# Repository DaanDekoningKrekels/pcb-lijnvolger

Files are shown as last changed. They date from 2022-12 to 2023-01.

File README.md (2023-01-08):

# PCB Lijnvolger

## Snelle links

- [Opdrachtomschrijving](./oo2-opdrachtbeschrijving.pdf)
- [Onderzoeksdocument](./onderzoeksdocument.md)
- [PCB-ontwerp](./src/kicad-project/)
- [Testplan bestukken printplaat](testplan.md)

## Project structuur

```
.
├── assets                  (figuren)
├── datasheets              (datasheets gebruikte componenten)
└── src                     (alle bronbestanden)
    ├── kicad-project       (PCB-ontwerp)
    ├── LEDD0-test          (test voor LED Drivers)
    ├── SENSE-0-1-test      (test voor eerste sensoren)
    ├── TinyLijnvolger      (finale code)
    └── WIRE-test           (test voor I2C verbinding)
```

## Verslag PCB-lijnvolger

In deze repository kan alle informatie teruggevonden worden rond dit project.

Lijnvolger werking GIF

Het onderzoeksdocument beschrijft de algemene verwachtingen voor dit project en hoe ik van plan was het aan te pakken. Ik denk dat het onderzoek vrij goed aansluit met hoe het project uiteindelijk is verlopen. Het jammere is dat ik de meeste code niet heb kunnen testen omdat I2C niet werkt. Dit is echter een softwareprobleem en ligt niet aan het ontwerp van de printplaat.

schema lijnvolger pcb
schema lijnvolger sensoren pcb

Zo zou de PCB eruit zien:

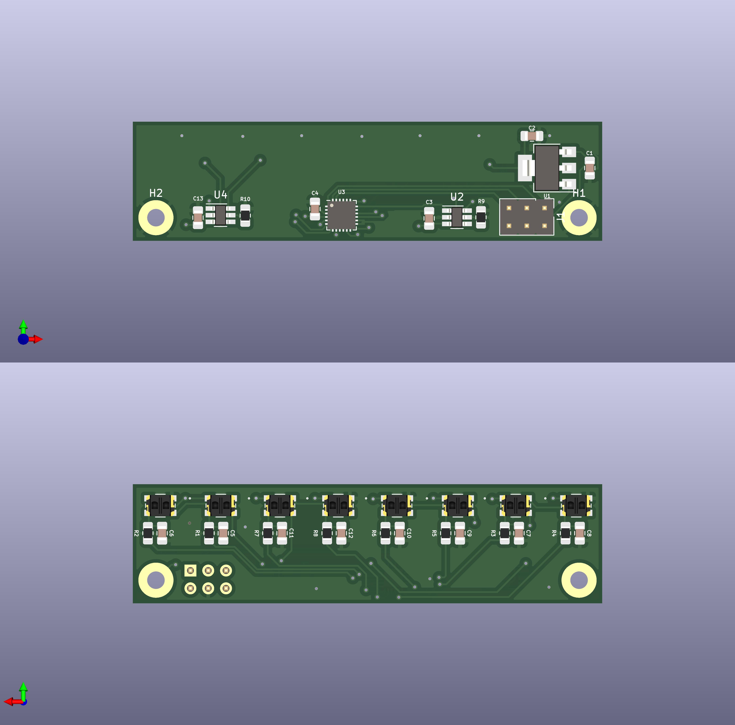
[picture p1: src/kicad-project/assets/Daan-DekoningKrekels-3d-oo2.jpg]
PCB lijnvolger render


Dit is hoe de definitieve printplaat eruit ziet:

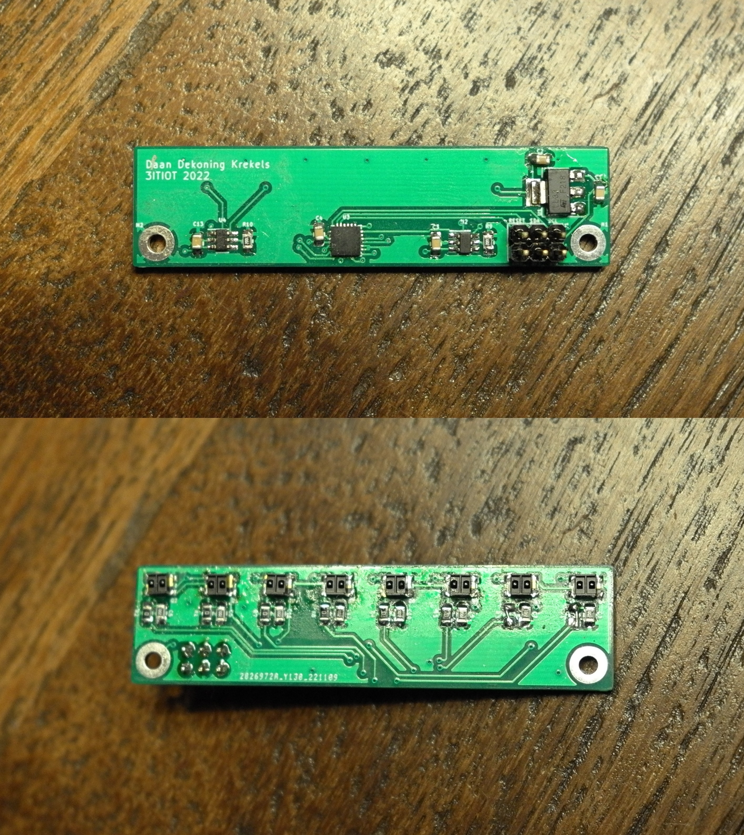
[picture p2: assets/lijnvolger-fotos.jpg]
fotos definitieve printplaat


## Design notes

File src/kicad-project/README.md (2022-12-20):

## Schema lijnvolger

Daan-DekoningKrekels-PCB-lijnvolgerDaan-DekoningKrekels-PCB-lijnvolger-sensors

## PCB lijnvolger

Daan-DekoningKrekels-3d-oo2

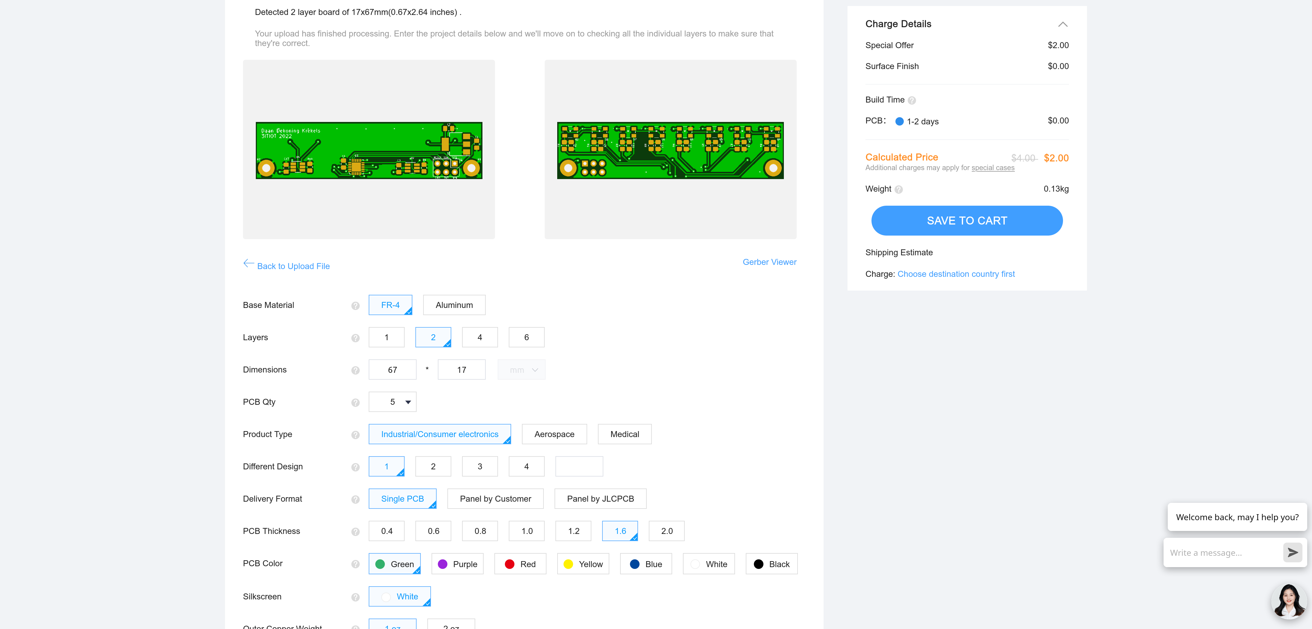
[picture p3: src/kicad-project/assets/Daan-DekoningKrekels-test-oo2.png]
Daan-DekoningKrekels-test-oo2


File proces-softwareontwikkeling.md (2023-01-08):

# Proces softwareontwikkeling

Zoals in het testplan te lezen is werd niet alle software in 1x geschreven. Er moesten incrementeel delen (individueel) getest worden om te weten of alles naar behoren werkt.

## Enkel MCU

Voor het programmeren van de MCU via de Arduino IDE is gekozen voor de [megaTinyCore](https://github.com/SpenceKonde/megaTinyCore) boardfiles. Dit project is immens goed gedocumenteerd en alles is terug te vinden op de eerder gelinkte GitHub pagina.

Het programmeren zelf verloopt via [jtag2updi](https://github.com/ElTangas/jtag2updi), een tool die het mogleijk maakt om met een Arduino NANO een UPDI microcontroller te programmeren. magaTinyCore heeft ondersteuning om jtag2updi als programmer te gebruiken. 

De code die hier gebruikt is is een simpele blinky op PC1. Dat is een pad voor een van de LED drivers dus ik kon met een multimeter gemakkelijk de spanning meten.

## I²C testen

Jammer genoeg is het mij niet gelukt om dit aan de praat te krijgen. Omdat ik de standaard TWI pinnen (PB0 en PB1) verkozen had voor de photointerruptors heb ik de ALT pinnen naar buiten gebracht om langs te verbinden.

Om een of andere reden is het mij echter niet gelukt om een I²C verbinding tot stand te brengen. Ik heb verschillende mogelijkheden getest en om de I²C verbinding te controleren heb ik een ESP32 gebruikt met een adres scanner. 

De Wire bibliotheek van megaTinyCore heeft een aantal extra functies om het gebruik van de alternatieve pinnen te faciliteren. ([documentatie](https://github.com/SpenceKonde/megaTinyCore/blob/master/megaavr/libraries/Wire/README.md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))
- `Wire.pins()` biedt de mogelijkheid om alternatieve pinnen expliciet aan te wijzen
  - De enige pinnen die hier kunnen worden meegegeven zijn de standaard TWI pinnen (PB0 en PB1) en de alternatieve pinnen (PA1 en PA2).
- `Wire.swap(n)` biedt de mogelijkheid ui te wisselen tussen een aantal voorgedefinieerde pinouts.
  - Voor de MCU die wij gebruiken is enkel `swap(0)` en `swap(1)` beschikbaar. 

Beide opties hebben I²C niet werkende gekregen in mijn geval. Als alternatief heb ik gezocht naar een manier om zelf de juiste pinout in te schakelen met een registermanipulatie. Die heeft echter ook niet geholpen. Op plaats 4 in het `PORTMUX` register `CTRLB` kan de alternatieve pinout worden ingeschakeld.

PORTMUX.CTRLB register

Als laatste redmiddel heb ik TinyCore geprobeerd. Die Wire bibliotheek biedt ook een manier om de alternatieve pinout te gebruiken. ([documentatie](https://docs.tinycore.dev/en/latest/usage.html#i2c)) 

`WIRE-test.ino`
```c++
// Wire Slave Sender

#include <Wire.h>

void setup() {
  // Deze functie zou de alternatieve pinout moeten activeren.
  // Wire.pins(18, 19);
  Wire.pins(PIN_PA1, PIN_PA2); 
  // Deze functie zou dit ook moeten doen
  Wire.swap(1); 
  // TWI ALT - Deze register schakelt de alternatieve pinout volgens de datasheet in
  PORTMUX.CTRLB |=   1 << 4; 

  // TinyCore: wisselen met alternatieve TWI pinnen
  Wire.useAlternatePins(); 

  Wire.begin(0x55);              // join i2c bus met adres 0x55
  Wire.onRequest(requestEvent);  // register event
}

void loop() {
  delay(100);
}

// function that executes whenever data is requested by master
// this function is registered as an event, see setup()
void requestEvent() {
  Wire.write("oi");  // respond with message of 2 bytes
  // as expected by master
}
```

## Photointerrupter testen

Ik heb telkens twee fotointerrupters in serie staan met elkaar dus ik ben gestart met één serieschakeling van de fotointerrupters te bestukken en testen. Met een camera is te zien of de LED's oplichten.

Later heb ik de code uitgebreid om ook de tweede LED-driver te testen.

```c++
#define LEDD0 13  // PC1
#define LEDD1 14  // PC2

void setup() {
  pinMode(LEDD0, OUTPUT);
  pinMode(LEDD1, OUTPUT);
}

void loop() {
  // put your main code here, to run repeatedly:
  digitalWrite(LEDD0, LOW); // IR LEDS gaan aan
  delay(500);
  digitalWrite(LEDD0, HIGH); // IR LEDS gaan uit
  delay(500);
  digitalWrite(LEDD1, LOW); // IR LEDS gaan aan
  delay(500);
  digitalWrite(LEDD1, HIGH); // IR LEDS gaan uit
  delay(500);
}
```

## Alles samenbrengen

In de finale code zal de lijnvolger een slave zijn waar de master een byte naar kan sturen om een bepaalde werkingsmodus in te schakelen of een aanvraag sturen om de data van de photointerruptors door te krijgen.

Via het `Wire.print()` statement zal een char array verstuurd worden. In deze char array zitten de actuele waardes van de photointerruptors.

Er zijn 4 modi beschikbaar:
1. `FAST_DIGITAL`: De IR LED's daar altijd aan staan en de master zal een byte array krijgen met 1en en 0en per sensor.
2. `FAST_ANALOG`: De IR LED's daar altijd aan staan en de master zal een byte array krijgen met de ADC waarde per sensor.
3. `ANALOG`: De IR LED's worden ingeschakeld op aanvraag en de master krijgt een byte array met de ADC waarde per sensor.
4. `DIGITAL`: De IR LED's worden ingeschakeld op aanvraag en de master krijgt een byte array met 1en en 0en per sensor.

De FAST-modi kunnen gebruikt worden om bijvoorbeeld sneller data te ontvangen waar de master nog een gemiddeldeberekening op uitvoert.

Idealiter zouden de DIGITAL-modi maar één byte doorsturen met op iedere bit de digitale waarde van de corresponderende photointerruptor.

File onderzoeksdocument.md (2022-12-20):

# Onderzoeksdocument – Lijnvolger

*Daan Dekoning Krekels*

## Geef een kritische analyse van je vorige PCB

> Werkte de PCB, heb je deze kunnen programmeren en data kunnen versturen over de I2C. 
>
> Als dit niet lukte, geef ook weer waarom.

Informatie over mijn printplaat kan je hier terugvinden: https://daandekoningkrekels.github.io/SmartSystems-RobotWagen/sensor-module/

Informatie over de bijhorende code hier: https://daandekoningkrekels.github.io/SmartSystems-RobotWagen/code/#sensor-module

Mijn PCB werkte niet, ik heb deze niet kunnen programmeren.

Over het algemeen denk ik dat de PCB vrij goed is gelukt eens de via's en clearances correct waren ingesteld.

Een grote moeilijkheid bij het bestukken van de print was dat er geen via's meer beschikbaar waren op school. De via's moest handmatig worden gemaakt door een stukje kabel te solderen in ieder gat. Hier had ik op voorhand geen weet van en dat resulteerde in het probleem dat bijvoorbeeld onder de microcontroller een aantal vias aanwezig zijn, die maken dat de MCU niet mooi vlak op de PCB staat en dat kan misschien op de lange termijn voor connectieproblemen zorgen.

KiCad gaat er, met de huidige instellingen, vanuit dat de gaten van through hole componenten beide kanten van de printplaat met elkaar verbinden. Dat is niet het geval waardoor ik bijvoorbeeld pin-headers en het through-hole kristal langs beide kanten moest solderen.

Het had beter geweest als ik op voorhand rekening had gehouden met deze beperkingen zodat ik geen via’s onder een IC heb en geen banen naar beide kanten van through-hole componenten.

Op volgende foto zie je dat mijn kristal iets hoger staat, dat is omdat ik langs beide kanten heb moeten solderen. Hetzelfde geldt voor de pinheaders, daarbij heb ik eerst de plastic isolatie naar boven gedaan en na het solderen terug tegen mijn printplaat gedrukt.

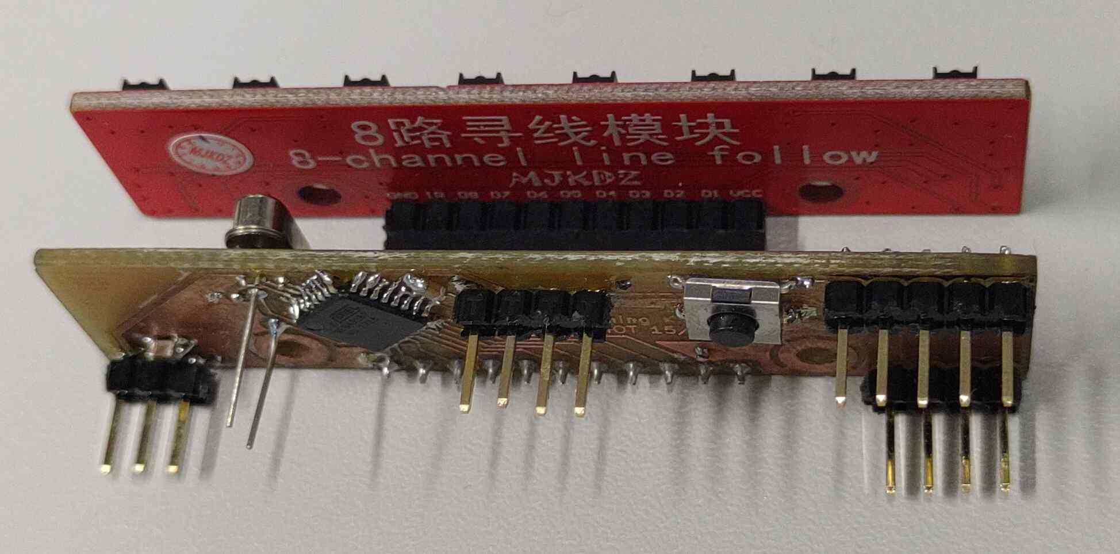
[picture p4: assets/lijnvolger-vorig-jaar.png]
 

## Welke aanpassing zou je maken in V2 i.k.v. de Smart Systems opdracht

> Als je nog een iteratie zou maken voor de opdracht van Smart Systems (niet PCB Design Advanced) welke verbeteringen zou je dan aanbrengen 

Als we de PCB terug zouden moeten frezen op school, zou ik meer rekening houden met de limietringen die daarbij van toepassing zijn. Zo zou ik bij pinheaders maar langs één kant banen trekken en via’s eerder in het midden van het bord zetten ipv. onder een IC. 

Op vlak van documentatie zou ik, als de PCB werkt, ook een gedetailleerde handleiding maken over hoe de bootloader kan geflasht worden.

Ik ben fan van de vormfactor dus die zou ik zeker behouden.

## Als je code hebt geschreven voor je project, voeg deze ook toe als zip 

> GitHub of andere online git repo is ook toegelaten

Informatie over de bijhorende code hier: https://daandekoningkrekels.github.io/SmartSystems-RobotWagen/code/#sensor-module

## Welke componten wordt er gebruikt ter detectie van lijn

> Zoek uit welke component er gebruik kan worden voor de lijn detectie. Zoek een zo gelijkaardige component. Voorzie een link naar een mogelijk leverancier (Farnell, Mouser, Digi-Key)

https://nl.farnell.com/sharp/gp2s700hcp/photointerrupter/dp/1618426

De MIR-3.0Y module bezit over 8 infrarood sensoren. Dit is een enkele component waarin een infrarood led zit en een infrarood phototransistor.

Een lijnvolger kan ook beschikken over een LED-driver. Die zorgt ervoor dat er altijd dezelfde stroom vloeit door de LED’s waardoor de helderheid constant is, ookal varieert de ingangsspanning. Een constante helderheid is belangrijk wanneer we de reflectie willen meten, de weerstand van de fototransistor zou anders totaal verkeerd zijn ten opzichte van de afstand.

## Op welke manieren kan de lijndetectie component worden aangestuurd

> Er zijn twee mogelijke manier om de lijn detectie module uit te lezen. Welke zijn dit? 
>
> Geef ook de nodige conditioneringscircuit om dit te doen, m.a.w. het deelschema rond de lijn detectie component 

Je kan lijnvolger-data op een digitale of analoge manier interpreteren. De fototransistor die in de sensor zit geeft een analoge spanning afhankelijk van de reflectie van het infrarood licht. Bij het andere type zal het logische niveau veranderen.

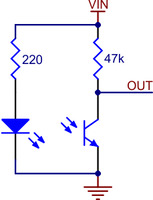
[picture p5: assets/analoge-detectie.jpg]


Er zijn verschillende manieren om dit te verwezenlijken. Voor de analoge spanning kan de uitgang van de fototransistor door een ADC gelezen worden. Door de Weerstand die naar de VIN gaat ontstaat er een spanningsdeler en zal dus de uitgangsspanning afhangen van de weerstand die de transistor heeft. Deze weerstand is uiteraard afhankelijk van de reflectie.

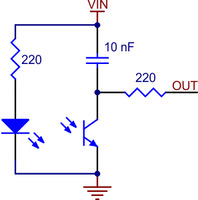
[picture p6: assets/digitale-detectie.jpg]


Voor de logische niveaus kan er gebruik gemaakt worden van een condensator naar de VIN. Wanneer er een puls gestuurd wordt vanuit de MCU zal de condensator opladen en geleidelijk aan weer ontladen, afhankelijk van de weerstand van de fototransistor. Door de lengte van deze ontlading te meten kunnen we achterhalen wat de reflectie is.

De analoge versie kan echter ook op andere manieren gebruikt worden. Zo kunnen we een normale digitale ingang gebruiken om zo de logische niveaus te weten. Hierbij hangen we af van wanneer de MCU een lijn als hoog of als laag beschouwt. Een andere optie is om een comparator te gebruiken en zo de analoge spanning om te zetten naar een hoge of lage uitgang.

Voor de printplaat kunnen we in principe opteren voor beide. Als de footprints worden voorzien voor de digitale schakeling kan, indien gewenst, ook enkel de pull-up weerstand worden geïnstalleerd en het andere pad kan met een 0 Ohm weerstand bestukt worden.

## Welke pinnen worden er gebruikt in mijn design en waarom

> Vele pinnen van een microcontroller hebben meestal een dubbele functionaliteit. In dit vooronderzoek ga je kijken welke pinnen het veiligste zijn om te gebruiken.

Om de lijnvolger aan te sluiten ga ik gebruik maken van **PA4**, **PA5**, **PA6**, **PA7**, **PB5**, **PB4** en **PB1**. De enable van de lijnvolger sluit ik aan op **PB0**.

De bedoeling is om met één enkele lijn code op te halen welke digitale pinnen hoog of laag zijn. Dat kan dan ook worden opgeslagen in één enkele byte.

Diezelfde byte kan gebruikt worden om via bit checking na te gaan welke sensor geactiveerd is.

**PA1** en **PA2** worden gebruikt voor de USART verbinding. Deze pinnen ondersteunen ook I²C dus dat is achteraf ook een mogelijkheid, mits toevoeging pull-up weerstand.

Voor UPDI zal **PA0** worden vrijgehouden en beschikbaar gemaakt via testpads.

De MAX6970AAE+ LED controller zorgt ervoor dat de LED’s, onafahanelijk van de ingangsspanning een constante helderheid hebben. Deze IC communiceert via SPI dus zal aangesloten worden op SCK = **PC0**, MISO = **PC1**, MOSI = **PC2**, load-enable = **PC3** en output-enbale = **P****B3**. Met een 360 Ohm weerstrand aan de SET pin zal de LED controller 50mA per LED toestaan. Deze waarde kan uiteraard worden ingesteld naar eigen wensen.

Load-Enable Input. Data is loaded transparently from the internal shift register to the output latch while LE is high. Data is latched into the output latch on LE’s falling edge and retained while LE is low.

Output-Enable Input. High forces outputs OUT0 to OUT7 high impedance without altering the contents of the output latches. Low enables outputs OUT0 to OUT7 to follow the state of the output latches.

## Hoe programmeer ik de microcontroller

> Onderzoek hoe je de microcontroller kan programmeren en werk dit praktisch uit

Net zoals de AtTiny 1616 ondersteunt de 3216 ook UPDI.

De ATtiny beschikt over een UPDI of Unified Program and Debug Interface. Deze biedt de mogelijkheid om via één enkele aansluiting de MCU te programmeren. Omdat deze aansluiting via de RESET pin gebeurt, geven we hier ook geen enkele GPIO pin voor op.

Deze interface biedt ook de mogelijkheid tot een   
 half-duplex UART-verbinding op te zetten om bijvoorbeeld debug informatie te kunnen tonen.

Voor het programmeren via deze interface hebben we minstens toegang nodig tot de RESET pin, VDD en GND. De Atmel-ICE kan gebruikt worden om het programma naar de MCU te schrijven.

## Welke clockconfiguratie gebruikt mijn design en waarom

> Een microcontroller heeft meestal verschillende opties voor het aansturen van interne clockmodel. Licht toe welke optie je gaat gebruiken en waarom. 

Omdat het geen concrete benodigdheid is om zo energiezuinig mogelijk te zijn zou ik gebruik maken van de interne 20MHz klok.

## Hoe wordt de PCB van stroom voorzien?

> Op welk spanningsniveau zal je PCB werken, Hoe ga je het correcte voltage voorzien aan de horloge. 

De PCB zal voorzien worden van de LDL1117S50R 5 V spanningsregelaar. De ingangsspanning kan dus 5,35 V tot 18 V bedragen. Overtollige spanning wordt in een lineaire regelaar afgestaan als warmte waardoor bij hoge spanningen ook hoge temperaturen gepaard gaan.

Er is gekozen voor een spanningsregelaar zodat deze rechtstreeks mee op de PCB kan staan, dicht bij de andere componenten. Zo vermijden we onstabiele en onbetrouwbare spanningen.

Echter, zal er ook een aansluiting zijn om rechtstreeks 5 V aan de PCB te voeden. Dit maakt de PCB toegankelijker bij gebruik met bijvoorbeeld een Arduino.

Uiteraard wordt ook voor iedere component een eigen ontkoppelcondensator voorzien zodat deze een stabiele ingangsspanning hebben.

## Bronnen

https://www.tinytronics.nl/shop/en/sensors/optical/infrared/8x-ir-line-tracking-module-40mm-range

https://www.pololu.com/product/4541

https://www.pololu.com/docs/0J19/1

## Datasheets:

Alle datasheets zijn ook beschikbaar in KiCad als je op een component staat en de 'D' indrukt.

https://datasheets.maximintegrated.com/en/ds/MAX6970.pdf

https://www.farnell.com/datasheets/53142.pdf

http://ww1.microchip.com/downloads/en/DeviceDoc/ATtiny3216-17-DataSheet-DS40002205A.pdf

https://www.farnell.com/datasheets/2259188.pdf

https://ww1.microchip.com/downloads/en/Appnotes/AN2519-AVR-Microcontroller-Hardware-Design-Considerations-00002519B.pdf

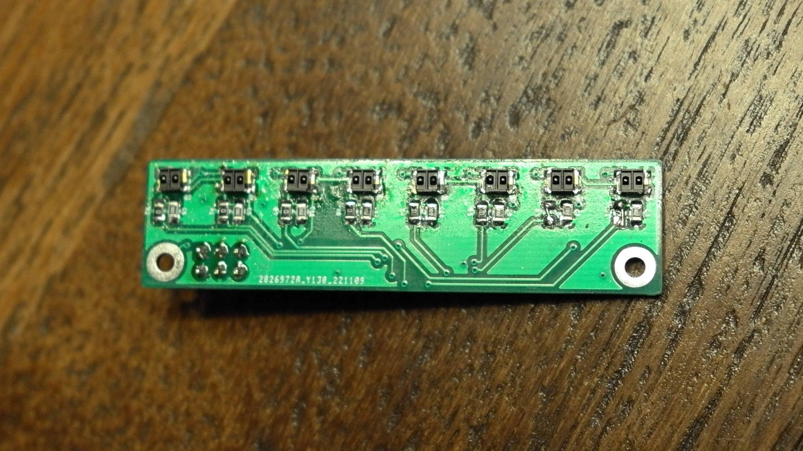
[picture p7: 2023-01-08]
assets/foto-onderkant.JPG

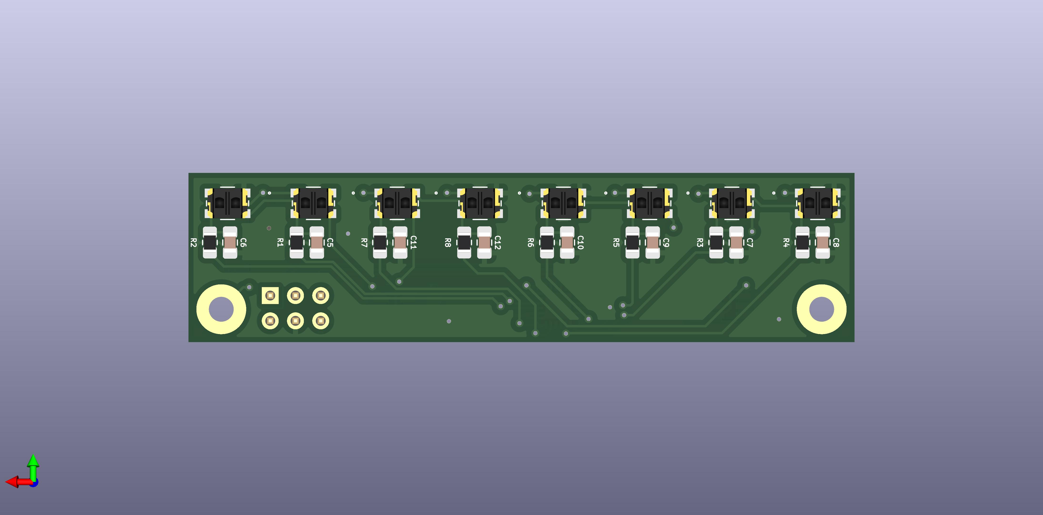
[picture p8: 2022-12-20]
src/kicad-project/assets/PCB-lijnvolger-onderkant.jpg

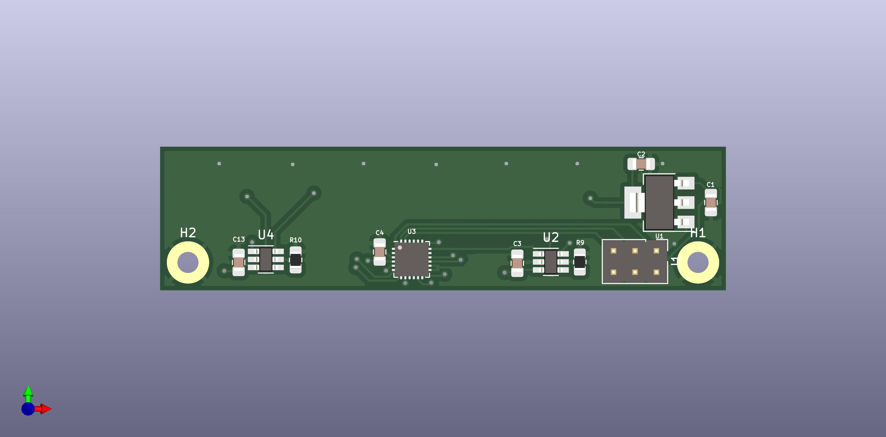
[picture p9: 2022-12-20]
src/kicad-project/assets/PCB-lijnvolger-bovenkant.jpg

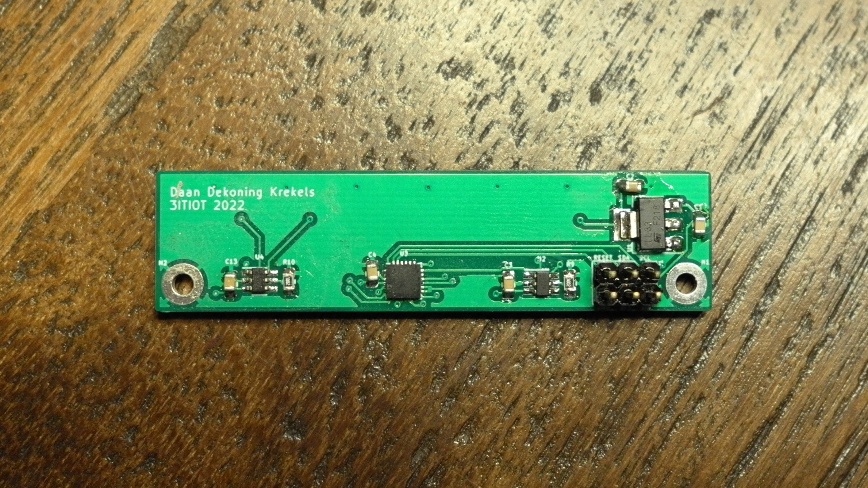
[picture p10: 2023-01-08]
assets/foto-bovenkant.JPG

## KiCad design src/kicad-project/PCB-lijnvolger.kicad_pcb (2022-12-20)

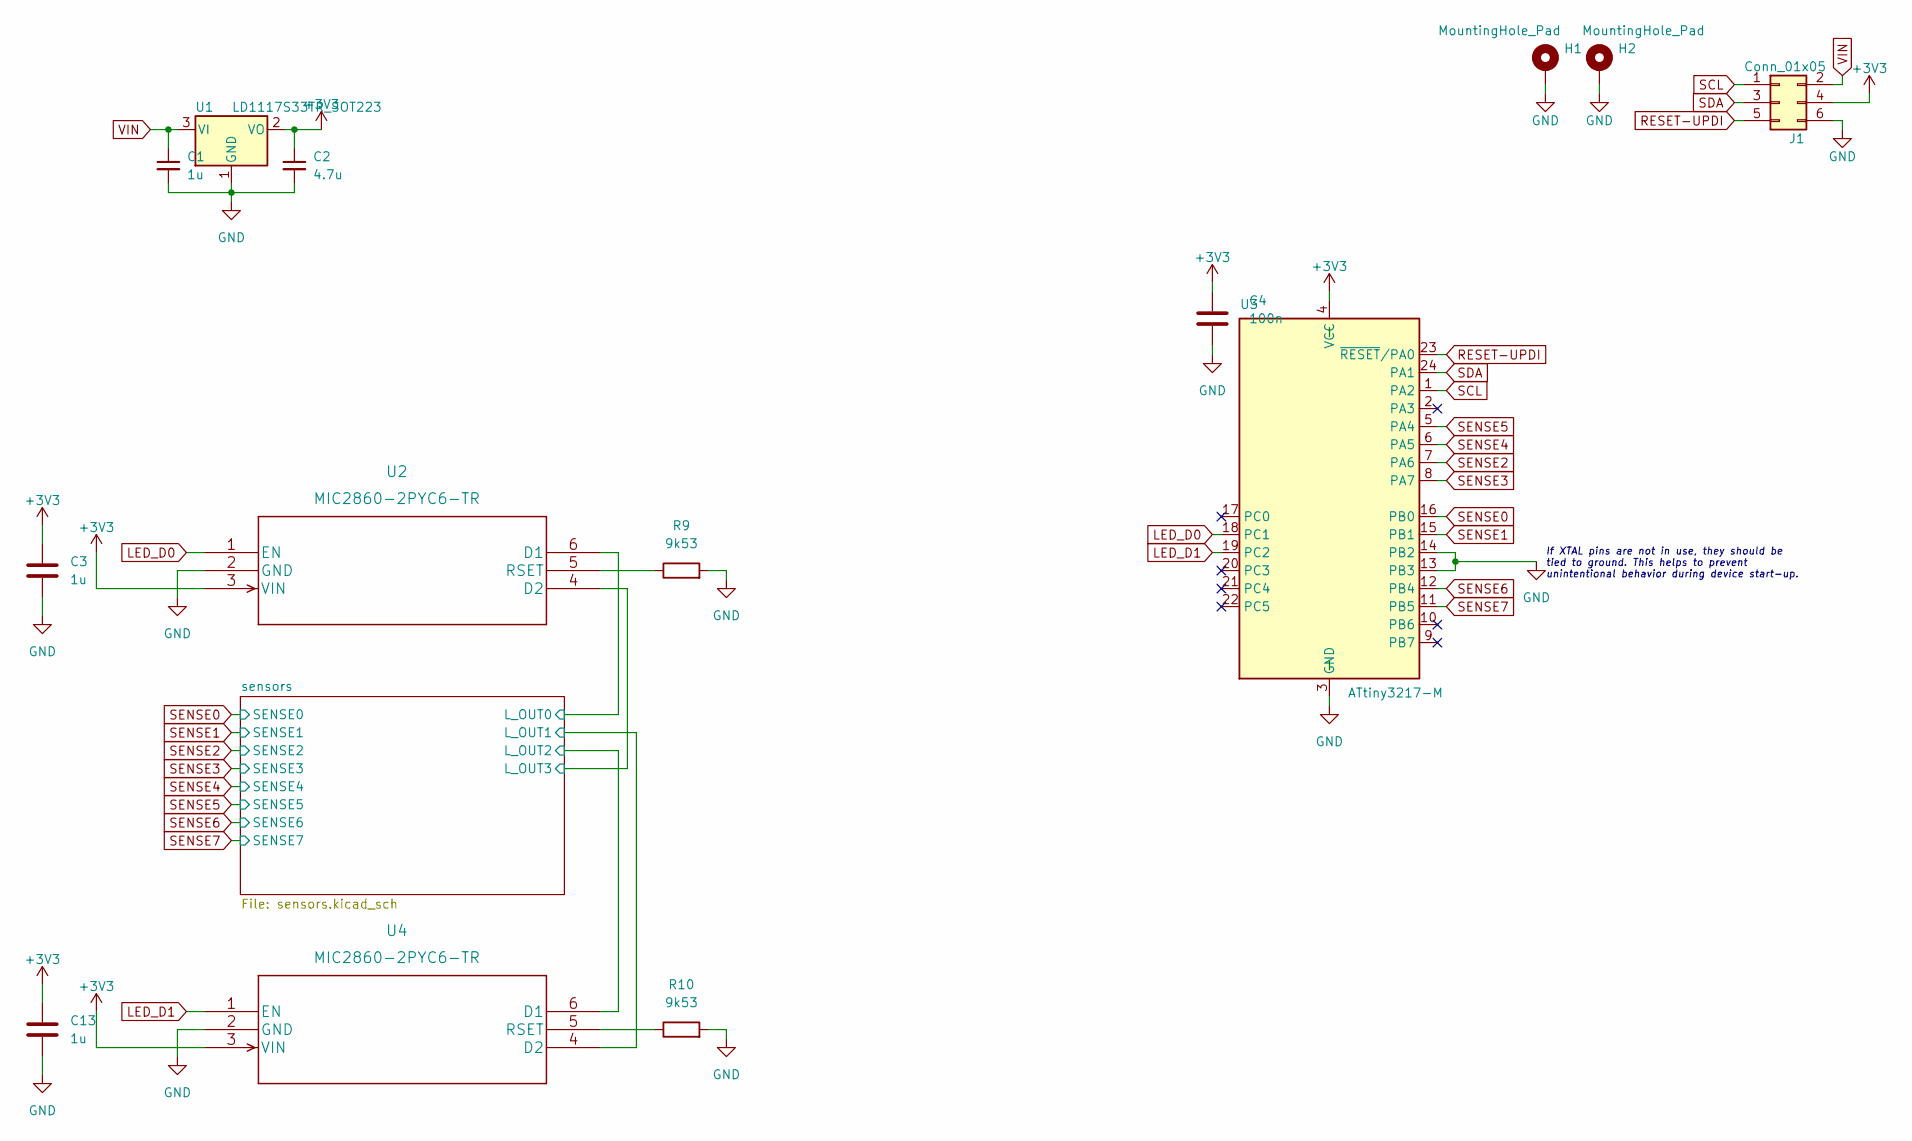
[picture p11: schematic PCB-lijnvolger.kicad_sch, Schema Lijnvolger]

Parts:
C1, C3, C13: 1u; C_0805_2012Metric_Pad1.18x1.45mm_HandSolder
C2: 4.7u; C_0805_2012Metric_Pad1.18x1.45mm_HandSolder
C4: 100n; C_0805_2012Metric_Pad1.18x1.45mm_HandSolder
H1, H2: MountingHole_Pad; MountingHole_2.5mm_Pad
J1: Conn_01x05; PinHeader_2x03_P2.54mm_Vertical
R9, R10: 9k53; R_0805_2012Metric_Pad1.20x1.40mm_HandSolder
U1: LD1117S33TR_SOT223; SOT-223-3_TabPin2
U2, U4: MIC2860-2PYC6-TR; SOT-23-6_Handsoldering
U3: ATtiny3217-M; QFN-24-1EP_4x4mm_P0.5mm_EP2.6x2.6mm

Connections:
+3V3: C2.1, C3.1, C4.1, C13.1, J1.4, U1.2 (VO), U2.3 (VIN), U3.4 (VCC), U4.3 (VIN); also elsewhere on the board
/sensors/L_OUT0: U2.6 (D1); also elsewhere on the board
/sensors/L_OUT1: U4.4 (D2); also elsewhere on the board
/sensors/L_OUT2: U4.6 (D1); also elsewhere on the board
/sensors/L_OUT3: U2.4 (D2); also elsewhere on the board
GND: C1.2, C2.2, C3.2, C4.2, C13.2, H1.1, H2.1, J1.6, R9.2, R10.2, U1.1 (GND), U2.2 (GND), U3.3 (GND), U3.13 (PB3), U3.14 (PB2), U3.25 (GND), U4.2 (GND); also elsewhere on the board
LED_D0: U2.1 (EN), U3.18 (PC1)
LED_D1: U3.19 (PC2), U4.1 (EN)
unnamed: R9.1, U2.5 (RSET)
unnamed: R10.1, U4.5 (RSET)
RESET-UPDI: J1.5, U3.23 (~RESET/PA0)
SCL: J1.1, U3.1 (PA2)
SDA: J1.3, U3.24 (PA1)
SENSE0: U3.16 (PB0); also elsewhere on the board
SENSE1: U3.15 (PB1); also elsewhere on the board
SENSE2: U3.7 (PA6); also elsewhere on the board
SENSE3: U3.8 (PA7); also elsewhere on the board
SENSE4: U3.6 (PA5); also elsewhere on the board
SENSE5: U3.5 (PA4); also elsewhere on the board
SENSE6: U3.12 (PB4); also elsewhere on the board
SENSE7: U3.11 (PB5); also elsewhere on the board
VIN: C1.1, J1.2, U1.3 (VI)

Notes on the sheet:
If XTAL pins are not in use, they should be tied to ground. This helps to prevent unintentional behavior during device start-up.

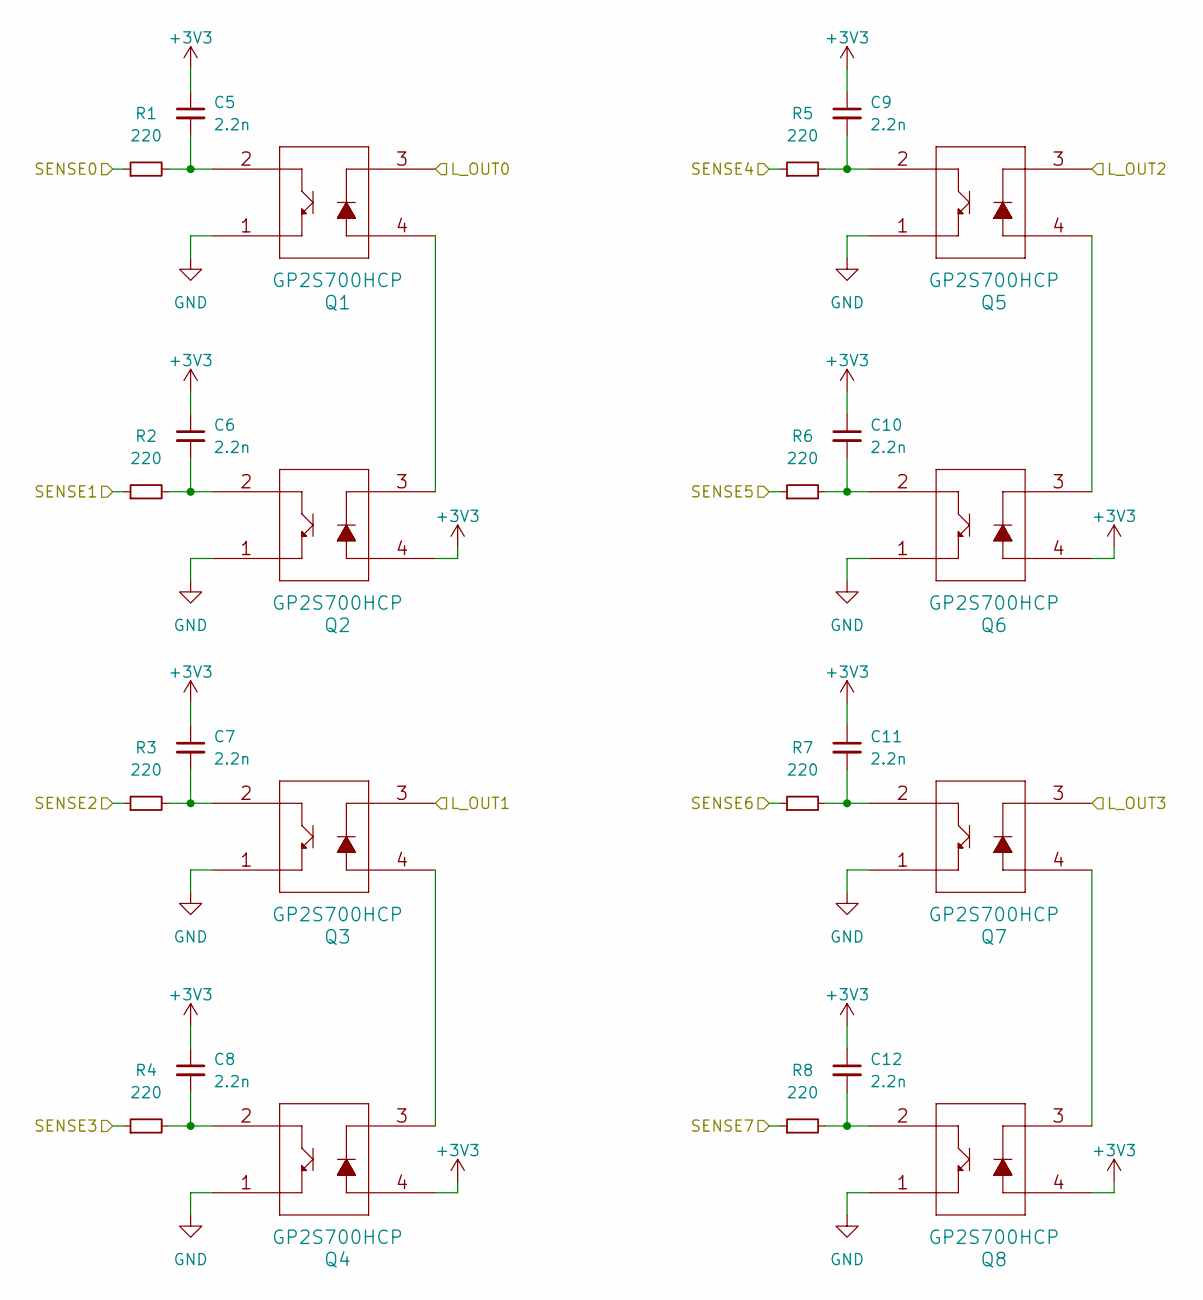
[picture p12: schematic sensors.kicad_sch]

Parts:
C5, C6, C7, C8, C9, C10, C11, C12: 2.2n; C_0805_2012Metric_Pad1.18x1.45mm_HandSolder
Q1, Q2, Q3, Q4, Q5, Q6, Q7, Q8: GP2S700HCP
R1, R2, R3, R4, R5, R6, R7, R8: 220; R_0805_2012Metric_Pad1.20x1.40mm_HandSolder

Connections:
+3V3: C5.1, C6.1, C7.1, C8.1, C9.1, C10.1, C11.1, C12.1, Q2.4, Q4.4, Q6.4, Q8.4; also elsewhere on the board
/sensors/L_OUT0: Q1.3; also elsewhere on the board
/sensors/L_OUT1: Q3.3; also elsewhere on the board
/sensors/L_OUT2: Q5.3; also elsewhere on the board
/sensors/L_OUT3: Q7.3; also elsewhere on the board
GND: Q1.1, Q2.1, Q3.1, Q4.1, Q5.1, Q6.1, Q7.1, Q8.1; also elsewhere on the board
unnamed: C5.2, Q1.2, R1.2
unnamed: C6.2, Q2.2, R2.2
unnamed: C7.2, Q3.2, R3.2
unnamed: C8.2, Q4.2, R4.2
unnamed: C9.2, Q5.2, R5.2
unnamed: C10.2, Q6.2, R6.2
unnamed: C11.2, Q7.2, R7.2
unnamed: C12.2, Q8.2, R8.2
unnamed: Q1.4, Q2.3
unnamed: Q3.4, Q4.3
unnamed: Q5.4, Q6.3
unnamed: Q7.4, Q8.3
SENSE0: R1.1; also elsewhere on the board
SENSE1: R2.1; also elsewhere on the board
SENSE2: R3.1; also elsewhere on the board
SENSE3: R4.1; also elsewhere on the board
SENSE4: R5.1; also elsewhere on the board
SENSE5: R6.1; also elsewhere on the board
SENSE6: R7.1; also elsewhere on the board
SENSE7: R8.1; also elsewhere on the board

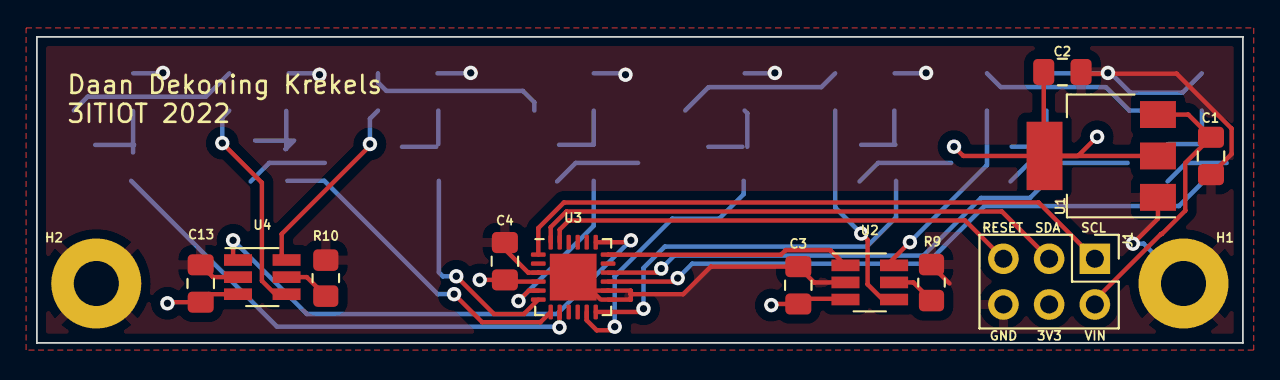
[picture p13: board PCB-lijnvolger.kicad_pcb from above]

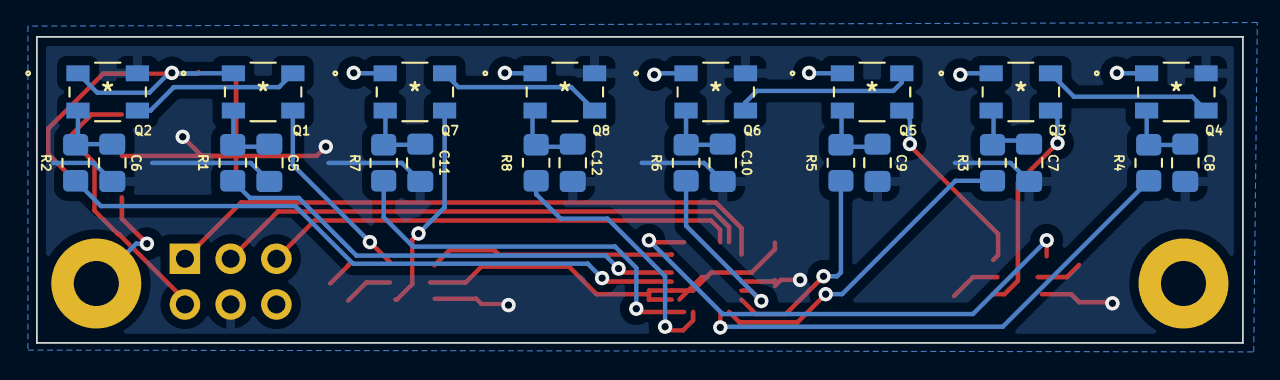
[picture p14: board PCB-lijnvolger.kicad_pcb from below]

Board: 2 copper layers, 67.0 x 17.0 mm, 38 parts (24 on the bottom side), 34 nets.

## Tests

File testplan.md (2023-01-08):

# Testplan PCB Lijnvolger

| **Volgorde** | **Fase** | **Taak of Test** | **Component** | **Beschrijving** | **Done, pass, fail** | **Opmerking** |
| --- | --- | --- | --- | --- | --- | --- |
| 1 | Power supply | Taak | U1, C1, C2 | Bestukken spanningsregelaar en ontkoppelcondensatoren. | Done | |
| 3 | Power supply | Test | U1, C1, C2 | Testen spanningsregelaar door een voeding van 5V te voorzien aan de VIN pin en 3,3V te meten aan de uitgang van de regelaar. | Done | Zonder problemen vanaf de eerste keer gelukt |
| 3 | MCU | Taak | U3, C4 | Bestukken MCU en ontkoppelcondensator. | Done | Het bestukken van de MCU ging niet goed bij de eerste keer. VCC en GND waren kortgesloten dus ik heb de MCU vervanger door een nieuwe na het desolderen. Bij het desolderen zijn ook wat paden mee losgekomen waardoor ik een nieuw exemplaar van mijn pcb heb moeten gebruiken. Ik heb bestukt met hetelucht. |
| 2 | MCU | Test | U3, C4 | Testen MCU door deze te programmeren met Arduino als UPDI programmer. | Done | Bij de tweede keer proberen is het gelukt. |
| 4 | MCU | Test | U3 | Testen of I2C verbinding tot stand kan komen met een andere MCU. | Fail | Het is me niet gelukt om I²C aan te praat te krijgen. Ik maak gebruik van de alternatieve TWI pinnen maar ik heb deze niet kunnen gebruiken. |
| 5 | LED drivers | Taak | U2, U4, C3, C13 | Bestukken LED drivers en ontkoppelcondensatoren. | Done | Ik heb de LED drivers probleemloss met een soldeerbout bestukt. |
| 6 | LED drivers | Test | U2, U4, C3, C13 | Testen LED drivers door een programma te schrijven voor de MCU die de leds laat pinken. Met een oscilloscoop is dan de spanning af te lezen, met een multimeter kan de kortsluitstroom gemeten worden om te zien of I_led goed is ingesteld. | Done | Ik heb de uitgang van de LED drivers gemeten met een oscilloscoop die 3.3 V als referentie (massaaansluiting) heeft gekregen.  Dat heb ik gedaan omdat de LED driver de massa schakelt en niet de voedingsspanning. |
| 7 | Photointerrupter | Taak | Q1, R2, C6 | Bestukken photointerrupter Q1 en nevencomponenten. | Done | |
| 8 | Photointerrupter | Test | Q1, R2, C6 | Een enkele photointerrupter bestukken om te testen of deze aan te sturen en uit te lezen zijn vanaf de MCU. | Done | Ik heb telkens twee fotointerrupters in serie staan met elkaar dus ik ben gestart met één serieschakeling van de fotointerrupters te bestukken en testen. Met een camera is te zien of de LED's oplichten. |
| 9 | Photointerrupter | Taak | Q2, Q3, Q4, Q5, Q6, Q7, Q8 +  R1, R2, R3, R4, R5, R6, R7, R8, C5, C6, C7, C8, C9, C10, C11, C12 | Bestukken andere photointerrupters en nevencomponenten. | Done | |
| 10 | Photointerrupter | Test | Q2, Q3, Q4, Q5, Q6, Q7, Q8 +  R1, R2, R3, R4, R5, R6, R7, R8, C5, C6, C7, C8, C9, C10, C11, C12 | Andere photointerrupter testen of deze aan te sturen en uit te lezen zijn vanaf de MCU. | Done | Alle fotointerruptors werken! |

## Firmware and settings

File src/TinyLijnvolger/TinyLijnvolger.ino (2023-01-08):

#include <Wire.h>


#define LEDD0 PIN_PC1  // PC1
#define LEDD1 PIN_PC2  // PC2

#define AANTAL_SENSE_PINS 8
#define SENSE0 PIN_PB0  // PB0
#define SENSE1 PIN_PB1  // PB1
#define SENSE2 PIN_PA6  // PA6
#define SENSE3 PIN_PA7  // PA7
#define SENSE4 PIN_PA5  // PA5
#define SENSE5 PIN_PA4  // PA4
#define SENSE6 PIN_PB4  // PB4
#define SENSE7 PIN_PB5  // PB5

const byte SENSE_PINS[AANTAL_SENSE_PINS] = { SENSE0, SENSE1, SENSE2, SENSE3, SENSE4, SENSE5, SENSE6, SENSE7 };
char readings_to_send[AANTAL_SENSE_PINS];

// De master kan verschillende werkingsmodi selecteren door een byte te sturen
// de FAST modi verbruiken meer stroom omdat de IR LED's daar altijd aan staan
// ANALOG stuurt een byte met de analoge waarde van de fotointerruptor
// DIGITAL stuurt een byte met 1 of 0
enum STATES { IDLE,
              FAST_DIGITAL,
              FAST_ANALOG,
              ANALOG,
              DIGITAL };
STATES current_state = IDLE;
STATES new_state = IDLE;

void setup() {
  pinMode(LEDD0, OUTPUT);
  pinMode(LEDD1, OUTPUT);
  for (byte i = 0; i < AANTAL_SENSE_PINS; i++) {
    pinMode(SENSE_PINS[i], INPUT);
  }

  Wire.pins(PIN_PA1, PIN_PA2);
  Wire.begin(0x55);                 // join i2c bus met adres 0x55
  Wire.onRequest(requestEvent);     // register event
  Wire.onReceive(receiveNewState);  // give the Wire library the name of the function
}

void loop() {
  if (new_state != current_state) {
    switch (new_state) {
      case FAST_ANALOG:
        digitalWrite(LEDD0, LOW);  // IR LEDS gaan aan
        digitalWrite(LEDD1, LOW);  // IR LEDS gaan aan

        break;
      case FAST_DIGITAL:
        digitalWrite(LEDD0, LOW);  // IR LEDS gaan aan
        digitalWrite(LEDD1, LOW);  // IR LEDS gaan aan

        break;
      case ANALOG:
        digitalWrite(LEDD0, HIGH);  // IR LEDS gaan uit
        digitalWrite(LEDD1, HIGH);  // IR LEDS gaan uit

        break;
      case DIGITAL:
        digitalWrite(LEDD0, HIGH);  // IR LEDS gaan uit
        digitalWrite(LEDD1, HIGH);  // IR LEDS gaan uit
        break;
      default:
        break;
    }
    current_state = new_state;
  }

  delay(1);
}

bool prepare_readings() {
  switch (new_state) {
    case FAST_ANALOG:
      read_pins_analog_fast();
      return true;
      break;
    case FAST_DIGITAL:
      read_pins_digital_fast();
      return true;
      break;
    case ANALOG:
      read_pins_analog();
      return true;
      break;
    case DIGITAL:
      read_pins_digital();
      return true;
      break;
    default:
      return false;
      ;
  }
}

void read_pins_analog_fast() {
    readings_to_send[0] = (char)analogRead(SENSE_PINS[0]);
    readings_to_send[1] = (char)analogRead(SENSE_PINS[1]);
    readings_to_send[2] = (char)analogRead(SENSE_PINS[2]);
    readings_to_send[3] = (char)analogRead(SENSE_PINS[3]);
    readings_to_send[4] = (char)analogRead(SENSE_PINS[4]);
    readings_to_send[5] = (char)analogRead(SENSE_PINS[5]);
    readings_to_send[6] = (char)analogRead(SENSE_PINS[6]);
    readings_to_send[7] = (char)analogRead(SENSE_PINS[7]);
}

// Idealiter maakt deze functie één byte met iedere bit de waarde van een pin
void read_pins_digital_fast() {
    readings_to_send[0] = (char)digitalRead(SENSE_PINS[0]);
    readings_to_send[1] = (char)digitalRead(SENSE_PINS[1]);
    readings_to_send[2] = (char)digitalRead(SENSE_PINS[2]);
    readings_to_send[3] = (char)digitalRead(SENSE_PINS[3]);
    readings_to_send[4] = (char)digitalRead(SENSE_PINS[4]);
    readings_to_send[5] = (char)digitalRead(SENSE_PINS[5]);
    readings_to_send[6] = (char)digitalRead(SENSE_PINS[6]);
    readings_to_send[7] = (char)digitalRead(SENSE_PINS[7]);
}

void read_pins_analog() {
  digitalWrite(LEDD0, LOW);  // IR LEDS gaan aan
  digitalWrite(LEDD1, LOW);  // IR LEDS gaan aan
  delay(10);

  for (byte i = 0; i < AANTAL_SENSE_PINS; i++) {
    readings_to_send[i] = (char)analogRead(SENSE_PINS[i]);
  }

  delay(10);
  digitalWrite(LEDD0, HIGH);  // IR LEDS gaan uit
  digitalWrite(LEDD1, HIGH);  // IR LEDS gaan uit
}

// Idealiter maakt deze functie één byte met iedere bit de waarde van een pin
void read_pins_digital() {
  digitalWrite(LEDD0, LOW);  // IR LEDS gaan aan
  digitalWrite(LEDD1, LOW);  // IR LEDS gaan aan
  delay(10);

  for (byte i = 0; i < AANTAL_SENSE_PINS; i++) {
    readings_to_send[i] = (char)digitalRead(SENSE_PINS[i]);
  }

  delay(10);
  digitalWrite(LEDD0, HIGH);  // IR LEDS gaan uit
  digitalWrite(LEDD1, HIGH);  // IR LEDS gaan uit
}

// Aanvraag voor de waarde van de fotointerrupters
void requestEvent() {
  if (prepare_readings()){
    Wire.print(readings_to_send);  // respond with message of 8 bytes
  }else{
    Wire.write(0x00);
  }
}

// Wanneer de master een nieuwe status doorgeeft
void receiveNewState(int16_t numBytes) {  // the Wire API tells us how many bytes
  if (numBytes == 1) {
    new_state = STATES(Wire.read());
  }
}

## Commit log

2022-12-20 projectbestanden lijnvolger
    [PCB-lijnvolger-B_Cu.gbl, PCB-lijnvolger-B_Mask.gbs, PCB-lijnvolger-B_Paste.gbp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]
2022-12-20 verduidelijking schema en pcb in kicad map

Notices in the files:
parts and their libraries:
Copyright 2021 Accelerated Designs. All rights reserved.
